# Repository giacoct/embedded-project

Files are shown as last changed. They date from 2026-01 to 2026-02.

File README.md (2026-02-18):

# Embedded Software fo the IoT - project group 23 - SUNFLOWER
A solar tracking system using light-sensing logic to maximize energy harvesting. Controlled automatically measuring light, or manually through joystick or webapp.

Our code works as a finite state machine that is linked to a **manual**, **automatic** and **web-control** operating modes.
You can access the web-control mode via the wifi generated by the esp32: "SOLAR_MOBILE" (we reccommend changing the password in the code). Then, access the web-control page on the address: `192.168.4.1` by typing it into your browser.  
Here you can see that you can switch between modes with the toggle switch. You can also switch between modes by clicking the joystick.

The porpouse of the automatic mode is to get the best possible illumination on our panels.
You can customize the various parameters to modify how fast the motors move and how sensitive the sensors are.

<div style="width:70%; margin: auto;">

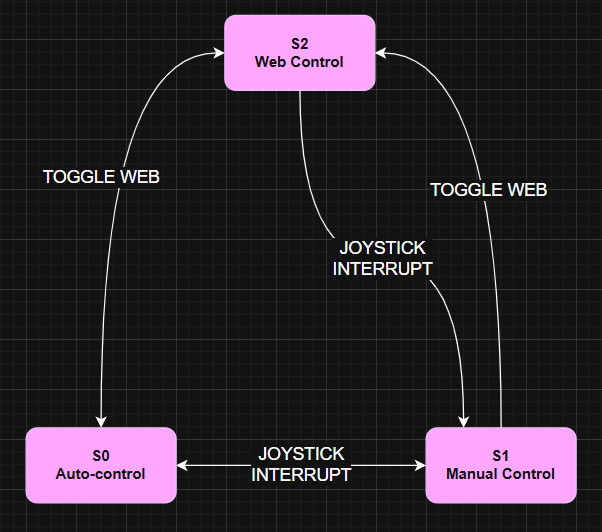
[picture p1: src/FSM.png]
Finite State Machine diagram

</div>

**Project Members**: Matteo Zambon, Alessandro Weber, Giacomo Castellan.

## Requirements
You will need to download the following libraries:
- [AsyncTCP.h](https://github.com/ESP32Async/AsyncTCP)
- [ESPAsyncWebServer.h](https://github.com/ESP32Async/ESPAsyncWebServer)

### Bill of Materials
- 1 _ESP32 S3_ board
- 1 Positional servo motor
- 1 Continuous servo motor
- 1 Slip ring (8 wires)
- 1 Solar panel
- 4 Photoresistors
- 3D prited parts &rarr; [at this link](https://www.printables.com/model/1574943-sunflower-project)

## Instructions
- You just have to print your 3D model and assemble it (more instructions at the link above).
- Then connect the cables as seen in the electrical scheme below:
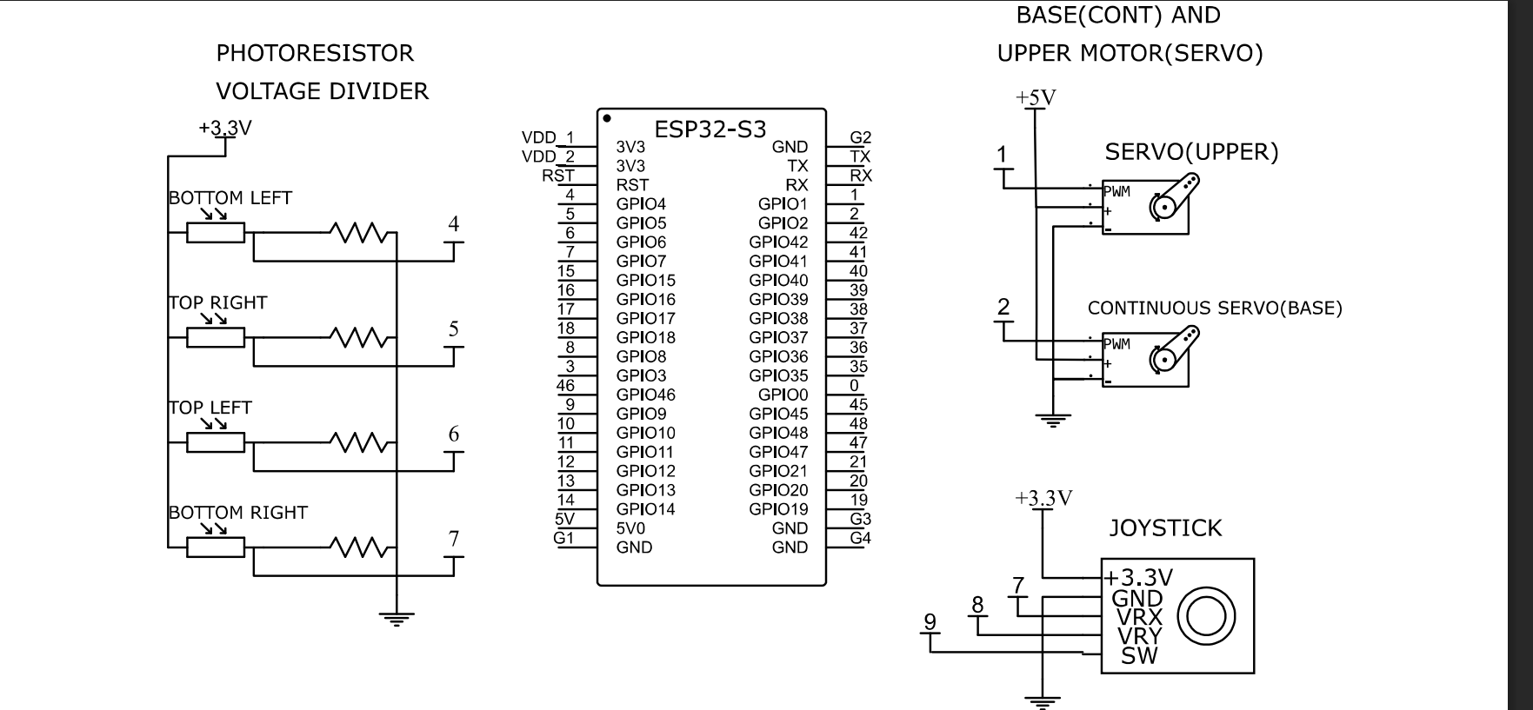
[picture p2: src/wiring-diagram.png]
wiring diagram

- Set up your Arduino IDE by: 
  - Installing the esp32 board &rarr; [follow this guide](https://randomnerdtutorials.com/installing-the-esp32-board-in-arduino-ide-windows-instructions/).
  - Installing the additional libraries previously downloaded.
- Finally, upload the _esp32_solar_station_ code using your Arduino IDE.  
  ⚠️ Note that you should upload the sketch with the following parameters set on Arduino IDE:

### Arduino IDE Setup (tools)

> You should check the following setting with the ones provied by the manufacturer.

- Board: "ESP32S3 Dev Module"
- **USB CDC On Boot**: "Enabled"
- **CPU Frequency**: "240MHz (WiFi)"
- Core Debug Level: "None"
- USB DFU On Boot: "Disabled"
- Erase All Flash Before Sketch Upload: "Disabled"
- Events Run On: "Core 1"
- **Flash Mode**: "QIO 80MHz"
- **Flash Size**: "16MB (128Mb)"
- JTAG Adapter: "Disabled"
- Arduino Runs On: "Core 1"
- USB Firmware MSC On Boot: "Disabled"
- **Partition Scheme**: "Default 4MB with spiffs (1.2MB APP/1.5MB SPIFFS)"
- **PSRAM**: "OPI PSRAM"
- **Upload Mode**: "UART0 / Hardware CDC"
- Upload Speed: "921600"
- USB Mode: "Hardware CDC and JTAG"
- Zigbee Mode: "Disabled"

## Project Structure

```code
embedded-project
│   README.md
│   website.html
│   wiring-diagram.png
│
├───esp32_solar_station
│       esp32_solar_station.ino
│       lightControl.cpp
│       lightControl.h
│       motorController.cpp
│       motorController.h
│       website.cpp
│
└───testing
        PID tuning.py
        pid_constants.json
        ws_client - send noweb.py
        ws_client - test.js
        ws_server - echo.py
```

### Sources:
- ESP32-S3 documentation:
  - [ESP32-S3-DevKitC-1](https://docs.espressif.com/projects/esp-dev-kits/en/latest/esp32s3/esp32-s3-devkitc-1/user_guide_v1.1.html)
  - [ESP-IDF Programming Guide](https://docs.espressif.com/projects/esp-idf/en/latest/esp32s3/get-started/index.html)
  - [Arduino ESP32](https://docs.espressif.com/projects/arduino-esp32/en/latest/index.html)
- Webserver & websocket for esp32: https://lastminuteengineers.com/esp32-websocket-tutorial/
- Esp32 PWM Basicis: https://lastminuteengineers.com/esp32-pwm-tutorial/
- ledc docs: https://espressif-docs.readthedocs-hosted.com/projects/arduino-esp32/en/latest/api/ledc.html#

### Who did what

| Giacomo | Matteo | Alessandro |
|:---|:---|:---|
| ESP code (libraries and main) | ESP code (libraries and main) | ESP code (libraries and main) |
| 3D model and printing | HTML development | HTML development |
| Finite state machine | Finite state machine | Video |
| Video | Presentation | Electrical scheme |

## Presentation
- [Video](https://youtu.be/n94C179-7IY)
- [Presentation](https://drive.google.com/file/d/1SDzr-Ak0xUK7H76m8eDZOuBcJwM7BU4j/view?usp=drive_link)

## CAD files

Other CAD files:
3D files/servo_holder.f3d
drawingz/servo_holder.f3d

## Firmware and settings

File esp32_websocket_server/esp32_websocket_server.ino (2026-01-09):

/* Requirements
 *  => ESPAsyncWebServer: https://github.com/ESP32Async/ESPAsyncWebServer/
 *  => AsyncTCP: https://github.com/ESP32Async/AsyncTCP/
*/
#include <WiFi.h>
#include <AsyncTCP.h>
#include <ESPAsyncWebServer.h>
#include "website.cpp"
#include "motorController.h"
#include "lightControl.h"

const char *ssid = "SOLAR_MOBILE";
const char *password = "militarygrade";

const double kBasePID[] = {0.05, 0.0000000000, 0.0};
const double kServoPID[] = {0.05, 0.0000000000, 0.0};

// servo and base controller
MotorController mc = MotorController(8, 3, 0.01);
// photoresistors
LightControl tl = LightControl(6, 1788);
LightControl tr = LightControl(5, 2369);
LightControl bl = LightControl(4, 2880);
LightControl br = LightControl(7, 2514);

// joystick pins
const uint8_t joystickPin_x = 9;
const uint8_t joystickPin_y = 10;
const uint8_t joystickButtonPin = 11;

// solar Tracking Logic
int threshold = 100;  // Sensitivity: minimum difference in light to move
uint64_t t_auto = 0;

// joystick control
float joystickOld_x = 0.0, joystickOld_y = 0.0;
bool buttonPressed = false;
uint64_t t0 = 0;
// state variable
int state = 0;  // 0-auto,1-move to optimal,2-reset threshold,3-joystick,4-websocket

// AsyncWebServer object on port 80
AsyncWebServer server(80);
AsyncWebSocket ws("/ws");

// current production mex
uint64_t ts;
int solar = 50;

// function prototypes - optimization
void onEvent(AsyncWebSocket *server, AsyncWebSocketClient *client, AwsEventType type, void *arg, uint8_t *data, size_t len);
void handleWebSocketMessage(void *arg, uint8_t *data, size_t len);
void joystickControl();
long mapWithCenter(long x, long in_min, long in_center, long in_max, long out_min, long out_max);
void IRAM_ATTR joystickClick();
void solarTrackerLogic();


void solarTrackerLogic() {
  // Low value = light
  tl.sample();
  tr.sample();
  bl.sample();
  br.sample();

  Serial.printf("TL: %04d  TR: %04d  BL: %04d  BR: %04d \t", tl.read(), tr.read(), bl.read(), br.read());

  double baseErr = (tl.read() + bl.read() - tr.read() - br.read()) / 2.0;
  double servoErr = (tl.read() + tr.read() - bl.read() - br.read()) / 2.0;
  mc.moveWithPID(baseErr, -servoErr);

  // // --- CONTROLLO Y (TILT - Servo Standard) ---
  // // Se Top è più luminoso di Bottom (valore numerico PIÙ BASSO = più luce)
  // // avgTop < avgBot
  // if (abs(avgTop - avgBot) > threshold) {
  //   if (avgTop < avgBot) {
  //     Serial.printf("move up \t");
  //     // mc.setServoSpeed(1);
  //   } else {
  //     Serial.printf("move down \t");
  //     // mc.setServoSpeed(-1);
  //   }
  // } else {
  //   mc.setServoSpeed(0);
  // }

  // // --- CONTROLLO X (BASE - Servo Continuo) ---
  // // avgLeft < avgRight
  // if (abs(avgLeft - avgRight) > threshold) {
  //   if (avgLeft < avgRight) {
  //     Serial.printf("move left \t");
  //     // mc.setBaseSpeed(-1);
  //   } else {
  //     Serial.printf("move right \t");
  //     // mc.setBaseSpeed(1); // ruota a destra
  //   }
  // } else {
  //   mc.setBaseSpeed(0);
  // }
  Serial.println();
}

// interrupt
void IRAM_ATTR joystickClick() {
  unsigned long t1 = millis();
  if (t1 - t0 > 500) {  // 500 = debounce
    buttonPressed = true;
    t0 = t1;
  }
}

long mapWithCenter(long x, long in_min, long in_center, long in_max, long out_min, long out_max) {
  const long center = (out_min + out_max) / 2;
  if (x < in_center)
    return map(x, in_min, in_center, out_min, center);
  else
    return map(x, in_center, in_max, center, out_max);
}

void joystickControl() {
  long read_x = mapWithCenter(analogRead(joystickPin_x), 0, 1773, 4095, -10, 10);
  long read_y = mapWithCenter(analogRead(joystickPin_y), 0, 1751, 4095, -10, 10);

  // dead zone
  read_x = (abs(read_x) <= 1) ? 0 : read_x;
  read_y = (abs(read_y) <= 1) ? 0 : read_y;

  // update base speed only if joystick_x moved
  if (read_x != joystickOld_x) {
    joystickOld_x = float(read_x);
    mc.setBaseSpeed(read_x);
  }
  // update servo speed only if joystick_y moved
  if (read_y != joystickOld_y) {
    joystickOld_y = float(read_y);
    mc.setServoSpeed(read_y);
  }
}

void handleWebSocketMessage(void *arg, uint8_t *data, size_t len) {  // called on websocket's incoming message
  AwsFrameInfo *info = (AwsFrameInfo *)arg;
  if (info->final && info->index == 0 && info->len == len && info->opcode == WS_TEXT) {
    data[len] = 0;

    // code executed when a new message arrives from the ws
    String payload = String((char *)data);
    if (payload.startsWith("#cord#") && state == 4) {  // catch control data for the motors
      mc.setBaseSpeed(payload.substring(7, payload.indexOf(';')).toInt());
      mc.setServoSpeed(payload.substring(payload.indexOf(';') + 2).toInt());
      //Serial.printf("Mot:%f\tServo:%f\n", baseSpeed, servoSpeed);
    } else if (payload.startsWith("#toggle#") && state == 4) {
      state = 0;
      Serial.printf("da 4 passato allo stato 0 (controllo automatico)\n");
    } else if (payload.startsWith("#control#")) {
      Serial.printf("passato allo stato 4 (controllo web)\n");
      state = 4;
    } else {
      Serial.println(payload);  // print data recived from websocket
    }
  }
}

void onEvent(AsyncWebSocket *server, AsyncWebSocketClient *client, AwsEventType type, void *arg, uint8_t *data, size_t len) {
  switch (type) {
    case WS_EVT_CONNECT:
      Serial.printf("WebSocket client #%u connected from %s\n", client->id(), client->remoteIP().toString().c_str());
      break;
    case WS_EVT_DISCONNECT:
      Serial.printf("WebSocket client #%u disconnected\n", client->id());
      break;
    case WS_EVT_DATA:
      handleWebSocketMessage(arg, data, len);
      break;
    case WS_EVT_PONG:
    case WS_EVT_ERROR:
      break;
  }
}


void setup() {
  // Serial port for debugging purposes
  Serial.begin(115200);

  // motor control
  mc.begin();
  mc.tunePID(kBasePID, kServoPID);
  tl.begin();
  tr.begin();
  br.begin();
  bl.begin();

  // joystick pin setup
  pinMode(joystickPin_x, INPUT);
  pinMode(joystickPin_y, INPUT);
  pinMode(joystickButtonPin, INPUT_PULLUP);

  // interrupt on (joystick) button pin
  attachInterrupt(digitalPinToInterrupt(joystickButtonPin), joystickClick, FALLING);

  // initialize Wi-Fi
  WiFi.mode(WIFI_AP);
  IPAddress local_IP(192, 168, 4, 1);
  IPAddress gateway(192, 168, 4, 1);
  IPAddress subnet(255, 255, 255, 0);
  WiFi.softAPConfig(local_IP, gateway, subnet);
  WiFi.softAP(ssid, password);

  Serial.println("Access Point active!");
  Serial.print("IP: ");
  Serial.println(WiFi.softAPIP());

  // initialize websocket
  ws.onEvent(onEvent);
  server.addHandler(&ws);

  // Route for root / web page
  server.on("/", HTTP_GET, [](AsyncWebServerRequest *request) {
    request->send_P(200, "text/html", index_html);
  });
  server.begin();  // Start webserver

  // time for solar production
  ts = millis();
}

void loop() {
  ws.cleanupClients();  // delete disconnected clients

  switch (state) {
    case 0:  // autonomous control
      // if (millis() > t_auto + 100) {


      solarTrackerLogic();
      mc.moveBase();
      mc.moveServo();


      //   t_auto = millis();
      // }
      if (buttonPressed) {
        buttonPressed = false;
        state = 3;
        mc.stopAll();
        Serial.printf("da 0 passato allo stato 3 (controllo manuel)\n");
      }
      break;
    case 1:  // movement to optimal position
      if (buttonPressed) {
        buttonPressed = false;
        state = 3;
        mc.stopAll();
        Serial.printf("da 1 passato allo stato 3 (controllo manuel)\n");
      }
      break;
    case 2:  // reset threshold

      break;
    case 3:  // manual control with joystick
      joystickControl();
      mc.moveServo();
      mc.moveBase();
      if (buttonPressed) {
        buttonPressed = false;
        state = 0;
        mc.stopAll();
        Serial.printf("da 3 passato allo stato 0 (controllo automatico)\n");
      }
      break;
    case 4:  // manual control thru websocket
      mc.moveServo();
      mc.moveBase();
      if (buttonPressed) {
        buttonPressed = false;
        state = 3;
        ws.textAll("#no-web#");
        mc.stopAll();
        Serial.printf("da 4 passato allo stato 3 (controllo manuel)\n");
      }
      break;
    default:
      state = 0;
      break;
  }
  // solar production
  if (ts + 1000 < millis()) {
    String payload = "#solar=";
    payload = payload + String(solar) + "#";
    ws.textAll(payload);
    ts = millis();
  }
}

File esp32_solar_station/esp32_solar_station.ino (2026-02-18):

/* Requirements
 *  => ESPAsyncWebServer: https://github.com/ESP32Async/ESPAsyncWebServer/
 *  => AsyncTCP: https://github.com/ESP32Async/AsyncTCP/
*/
#include <WiFi.h>
#include <AsyncTCP.h>
#include <ESPAsyncWebServer.h>
#include "website.cpp"
#include "motorController.h"
#include "lightControl.h"

const char *ssid = "SOLAR_MOBILE";
const char *password = "password";

// servo and base controller
MotorController mc(8, 3, 0.0005);  // pin servo; pin base; kServo (higher is faster)
                                   // see the setup() to modify the mc constants

// photoresistors
LightControl tl(6, 1.300);    // LDR pin; gain
LightControl tr(5, 0.955);
LightControl bl(4, 0.860);
LightControl br(7, 1.008);

// joystick pins
const uint8_t joystickPinX = 9;
const uint8_t joystickPinY = 10;
const uint8_t joystickButtonPin = 11;

// joystick control
float joystickOldX = 0.0, joystickOldY = 0.0;
bool buttonPressed = false;
uint64_t t0 = 0;

// FSM state
uint8_t state = 0;

// AsyncWebServer object on port 80
AsyncWebServer server(80);
AsyncWebSocket ws("/ws");


// functions prototypes
void onEvent(AsyncWebSocket *server, AsyncWebSocketClient *client, AwsEventType type, void *arg, uint8_t *data, size_t len);
void handleWebSocketMessage(void *arg, uint8_t *data, size_t len);
long mapWithCenter(long x, long inMin, long inCenter, long inMax, long outMin, long outMax);
void IRAM_ATTR joystickClick();
void joystickControl();


void setup() {
  // Serial port for debugging purposes
  Serial.begin(115200);

  // light control init
  tl.begin();
  tr.begin();
  bl.begin();
  br.begin();

  // motor control init
  mc.begin();
  mc.kpBase = 0.5;
  mc.kpServo = 2.5;
  mc.deadzone = 80;

  // joystick pin setup
  pinMode(joystickPinX, INPUT);
  pinMode(joystickPinY, INPUT);
  pinMode(joystickButtonPin, INPUT_PULLUP);

  // interrupt on joystick button pin
  attachInterrupt(digitalPinToInterrupt(joystickButtonPin), joystickClick, FALLING);

  // initialize Wi-Fi
  WiFi.mode(WIFI_AP);
  IPAddress local_IP(192, 168, 4, 1);
  IPAddress gateway(192, 168, 4, 1);
  IPAddress subnet(255, 255, 255, 0);
  WiFi.softAPConfig(local_IP, gateway, subnet);
  WiFi.softAP(ssid, password);

  Serial.println("Access Point active!");
  Serial.print("IP: ");
  Serial.println(WiFi.softAPIP());

  // initialize websocket
  ws.onEvent(onEvent);
  server.addHandler(&ws);

  // Route for root / web page
  server.on("/", HTTP_GET, [](AsyncWebServerRequest *request) {
    request->send_P(200, "text/html", index_html);
  });
  server.begin();  // start webserver
}

void loop() {
  ws.cleanupClients();  // delete disconnected clients

  switch (state) {
    case 0:  // autonomous control
      {
        tl.update();
        tr.update();
        bl.update();
        br.update();

        int baseErr = (tl.read() + bl.read() - tr.read() - br.read());
        int servoErr = (bl.read() + br.read() - tl.read() - tr.read());

        mc.moveAuto(baseErr, servoErr);

        if (buttonPressed) {
          buttonPressed = false;
          state = 1;
          mc.stopMotors();
          Serial.println("State 3 - manual control");
        }
      }
      break;
    case 1:  // manual control with joystick
      {
        joystickControl();
        mc.moveMotors();

        if (buttonPressed) {
          buttonPressed = false;
          state = 0;
          mc.stopMotors();
          Serial.println("State 0 - autonomous control");
        }
      }
      break;
    case 2:  // manual control through websocket
      {
        mc.moveMotors();
        if (buttonPressed) {
          buttonPressed = false;
          state = 1;
          ws.textAll("#no-web#");
          mc.stopMotors();
          Serial.println("State 3 - manual control");
        }
      }
      break;
    default:
      {
        state = 0;
      }
      break;
  }
}



/* * * * * * * * * * *  FUNCTIONS  * * * * * * * * * * */

// handle client connections
void onEvent(AsyncWebSocket *server, AsyncWebSocketClient *client, AwsEventType type, void *arg, uint8_t *data, size_t len) {
  switch (type) {
    case WS_EVT_CONNECT:
      Serial.printf("WebSocket client #%u connected from %s\n", client->id(), client->remoteIP().toString().c_str());
      break;
    case WS_EVT_DISCONNECT:
      Serial.printf("WebSocket client #%u disconnected\n", client->id());
      break;
    case WS_EVT_DATA:
      handleWebSocketMessage(arg, data, len);
      break;
    case WS_EVT_PONG:
    case WS_EVT_ERROR:
      break;
  }
}

// called on websocket's incoming message
void handleWebSocketMessage(void *arg, uint8_t *data, size_t len) { 
  AwsFrameInfo *info = (AwsFrameInfo *)arg;
  if (info->final && info->index == 0 && info->len == len && info->opcode == WS_TEXT) {
    data[len] = 0;
    String payload = String((char *)data);

    // UNCOMMENT TO USE 'PID tuning.py' -> 'testing' folder
    /*
    if (payload.startsWith("#KB#")) {
      // base constant calibration
      mc.kpBase = payload.substring(4).toDouble();
    } else if (payload.startsWith("#KS#")) {
      // servo constant calibration
      mc.kpServo = payload.substring(4).toDouble();
    } else if (payload.startsWith("#DZ#")) {
      // deadzone calibration
      mc.deadzone = payload.substring(4).toInt();
    }
    */ 
    if (payload.startsWith("#cord#") && state == 2) {
      // catch control data for the motors
      mc.setBaseSpeed(payload.substring(7, payload.indexOf(';')).toInt());
      mc.setServoSpeed(payload.substring(payload.indexOf(';') + 2).toInt());
      //Serial.printf("Mot:%f\tServo:%f\n", baseSpeed, servoSpeed);
    } else if (payload.startsWith("#toggle#") && state == 2) {
      state = 0;
      //Serial.printf("Passato allo stato 0 (controllo automatico)\n");
    } else if (payload.startsWith("#control#")) {
      //Serial.printf("Passato allo stato 2 (controllo web)\n");
      state = 2;
    } else {
      Serial.println(payload);  // print data recived from websocket
    }
  }
}

int mapWithCenter(int x, int inMin, int inCenter, int inMax, int outMin, int outMax) {
  const int center = (outMin + outMax) / 2;
  if (x < inCenter)
    return map(x, inMin, inCenter, outMin, center);
  else
    return map(x, inCenter, inMax, center, outMax);
}

// joystick button interrupt
void IRAM_ATTR joystickClick() {
  unsigned long t1 = millis();
  if (t1 - t0 > 500) {  // 500 = debounce
    buttonPressed = true;
    t0 = t1;
  }
}
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

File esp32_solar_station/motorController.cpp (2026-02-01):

#include <Arduino.h>
#include "motorController.h"

MotorController::MotorController(uint8_t servoPin, uint8_t basePin, double kServo) {
  _servoPin = servoPin;
  _basePin = basePin;
  _kServo = kServo;

  _servoPos = zeroDC;
  _baseSpeed = 0;
  _servoSpeed = 0;
}

void MotorController::begin() {
  ledcAttach(_servoPin, pwmFreq, pwmRes);
  ledcAttach(_basePin, pwmFreq, pwmRes);
  stopMotors();
  t0 = millis();
}



void MotorController::setServoSpeed(int newSpeed) {
  _servoSpeed = constrain(newSpeed, -100, 100);
}
void MotorController::setBaseSpeed(int newSpeed) {
  _baseSpeed = constrain(newSpeed, -100, 100);
}

void MotorController::moveMotors() {
  // ----- move servo -----
  uint64_t t1 = micros();
  double deltaT = (t1 - t0) * 0.001;  // milliseconds
  t0 = t1;                            // save for the next cycle

  _servoPos += (double)(_servoSpeed)*deltaT * _kServo;
  _servoPos = constrain(_servoPos, minDC, maxDC);

  ledcWrite(_servoPin, (int)_servoPos);

  // ----- move base -----
  ledcWrite(_basePin, map(_baseSpeed, -100, 100, minDC, maxDC));  // maps to 12 instead of 10 to cap the speed of the base
}

void MotorController::stopMotors() {
  // ----- stop servo  -----
  _servoSpeed = 0;

  // ----- stop base  -----
  ledcWrite(_basePin, (maxDC + minDC) / 2);
  _baseSpeed = 0;
}



int MotorController::mapWithDeadZone(int x, int inMin, int inMax, int outMin, int outMax, int deadZone) {
  deadZone /= 2;  // I need only half the value of the deadZone
  if (x < -deadZone) {
    return map(x, inMin, -deadZone, outMin, 0);
  } else if (x > deadZone) {
    return map(x, deadZone, inMax, 0, outMax);
  } else {
    return 0;
  }
}

void MotorController::moveAuto(int baseError, int servoError) {
  // ----- auto-move servo -----
  servoError *= kpServo;
  setServoSpeed(mapWithDeadZone(servoError, -4095, 4095, -100, 100, deadzone));

  // ----- auto-move base -----
  baseError *= kpBase;
  if (_servoPos - zeroDC > 0) baseError = -baseError;
  setBaseSpeed(mapWithDeadZone(baseError, -4095, 4095, -100, 100, deadzone));

  // ----- apply movements -----
  moveMotors();
}

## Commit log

2025-10-16 websocket on esp32 working
2025-10-16 motor drive for h-bridge
2025-10-16 servo implementation
2025-10-17 solved merge confilct and updated readme
    [esp32_websocket_server.ino]
2025-10-21 Added BOM to readme
2025-10-23 pin change
2025-10-23 pin change v2
2025-10-23 better motor control + esp_ap
2025-10-23 Add small gears test details to README
2025-10-24 esp32_websocket_server refactor + comments added
2025-10-28 servo without servo library
2025-10-28 disegno servo_holder
    [servo_holder.f3d]
2025-10-29 added useful 3d files
    [servo_holder.f3d]
2025-11-04 Remove small gears test from README
    Removed small gears test entry from utilities section.
2025-11-04 libreria stepper
2025-11-04 testing servomotor with different drive
2025-11-05 joystick correction & servo drive working
    [esp32_websocket_server.ino]
2025-11-05 removed motor control from main
2025-11-11 rimosso custom stepper
2025-11-11 inizio stepper library applicata
2025-11-11 update with servo only
    Updated the bill of materials section to specify types of servo motors.
2025-11-11 init servo_only
2025-11-27 new class motorcontroll
2025-12-03 Button for solar control and manual control on website
2025-12-03 mateo ecco il push
2025-12-03 ennesimo push questa volta funziona la base
2025-12-03 gears gen link
2025-12-03 Non funzia il web (partire da disattivato)
2025-12-07 Revise project details and bill of materials
    Updated project description and added new components to the bill of materials.
2025-12-11 controllo automatico v2, problema con i pin/wifi
    [esp32_websocket_server.ino]
2025-12-11 Change ESP32 NodeMCU to ESP32 S3 in README
    Updated board information to specify ESP32 S3 with documentation link.
2025-12-11 Enhance ESP32 S3 board documentation in README
    Updated the documentation for the ESP32 S3 board to include links to both the development kit documentation and the programming guide.
2025-12-17 power display
2025-12-17 dono questi cambiamenti al progetto (fix dei pin)
    [esp32_websocket_server.ino]
2025-12-17 Refactor Arduino IDE setup section in README
2025-12-18 PID first partz
2025-12-18 pid code done,, issues to be corrected
    [esp32_websocket_server.ino, motorController.cpp]
2025-12-18 pid a little more advanced but still broken
    [esp32_websocket_server.ino, motorController.cpp]
2025-12-18 pid funzionante, da modificare i k e da impostare la calibrazione delle fotoresistenze con due punti
2026-01-09 PID k testing
2026-01-17 reformat + PID tuning tool
    [pid_constants.json]
2026-01-28 test ws receiving PID parameters
    [pid_constants.json]
2026-01-28 site and pid issues
    [esp32_solar_station.ino, motorController.cpp]
2026-01-30 directory refactoring
    [pid_constants.json]
2026-01-30 shitty calibration but new
2026-01-30 new photoresistor calibration
2026-01-31 only photoresistors work :(
    [pid_constants.json]
2026-02-01 working auto orienting
    [pid_constants.json]
2026-02-01 WORKING light follow - proportional + deadzone
    [pid_constants.json]
2026-02-09 Fix 3D parts link and update wiring diagram caption
    Updated the link for 3D printed parts and corrected image caption.
